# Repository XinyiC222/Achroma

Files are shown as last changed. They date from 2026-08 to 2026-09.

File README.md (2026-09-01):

# Achroma WORK IN PROGRESS

Achroma is a wireless reversible split keyboard with 36 keys that is powered by ZMK. It uses a nine!nano v2 replica from aliexpress. There are two versions of Achroma, the Choc/Choc_v2 compatible one, and the MX compatible one! This is still a work in progress. Theres only a case for the MX version. But there are two different pcb designs based on which one you want to use. Here is the ZMK source files: https://github.com/XinyiC222/zmk-achroma-config I made this after seeing countless split keyboard builds that people where making online and I wanted to join in on the fun! To use it you just have to turn on the on/off button that is connected to the battery. The pcb is designed in kicad and the case is modeled in Fusion360.

Screenshot 2026-08-30 at 11 53 14 AM
Screenshot 2026-08-30 at 11 56 21 AM (MX version)
<h1>Keymap</h1>
Screenshot 2026-08-30 at 11 53 38 AM
Screenshot 2026-08-30 at 11 53 43 AM
Screenshot 2026-08-30 at 11 53 48 AM

<h1>Resources</h1>
<h3>Footprints and References:</h3>

https://github.com/piit79/42keebs-kicad

https://flatfootfox.com/ergogen-part6-reversible-split/

https://github.com/kata0510/Lily58 (this has a great footprint library!)

https://github.com/aroum/PNCATEHO (reversible Choc footprints that fits both versions!)

<h3>Tools</h3>

https://www.keyboard-layout-editor.com/

https://nickcoutsos.github.io/keymap-editor/

https://github.com/adamws/kicad-kbplacer

Fusion360

Kicad

<h1>Mini Guide/ My Process (Work in progress)</h1>

Before starting, you should have already made some kind of electronic project prior to this. It would come off easier if you've designed a pcb before. Reading guides you find online can be super helpful. there are many resources that I didn't link but anything online is helpful. 

1. I first researched and wrote down what I wanted this project to look like at the end. Do I want it to be low profile or MX? Do I want this to be reversible? How much money do I want to spend on this? Do I want to make a custom layout, or do I want to use an existing one? Wireless? etc.
2. I ended up choosing to making my own layout and use ZMK for wireless. So I went ahead and looked for reversible footprints to use. I also wanted to use a battery for it. I then went into keyboard layout editor and made my desired layout.( I only made the left side first)
3. Then I created the schematics in kicad. It included a jst pin, a reversible nice!nano, choc/mx switches, LED, slide switch, and a reset button.
4. then using the .json file from the layout I made in keyboard layout editor and the kbplacer, I organized the keys for the left split.
5. spent a lot of time between editing the schematics, the pcb, and testing new footprint libraries. After a ton of trial and error I made the general layout I wanted.  Screenshot 2026-08-14 at 11 48 46 PM

6. Exported the gerber files and imported them into jlc pcb.
7. I then added 3d models to each of the footprints and import it into fusion to make the case(MX only) Screenshot 2026-08-16 at 12 56 51 PM

8. I looked for components in aliexpress
9. Then I started reading through how to set up ZMK and made the firmware using github actions.
10. After you assemble the pcb and have printed the case out, use a M2 heat insert on all the holes in the case(5 total). Then place the pcb on top and use a M2 screw to tighten it in place.
11. Once you've build the physical item, flash the firmware into the devices. You can learn more about it in the ZMK docs. If you'll like to use the firmware provided, please head to the Firmware folder to download what i have for both the left and the right side.
Screenshot 2026-08-30 at 11 56 32 AM

<h1>Schematic</h1>
Screenshot 2026-09-01 at 12 18 42 PM

<PCB>
Screenshot 2026-09-01 at 12 19 13 PM
Screenshot 2026-09-01 at 12 19 52 PM
Screenshot 2026-09-01 at 12 19 33 PM
Screenshot 2026-09-01 at 12 20 06 PM

<h1>BOM</h1>

Here's the BOM! The Quantity listed below are the amount you need. The links included come in bulks and vary depending on how much you are buyinh. All listed items are required for the build.

| Item | Purpose | Price | Quantity | Source |
| :--- | :--- | :--- | :--- | :--- |
| Nice!Nano V2.0 | Micro controller | $1.95 | 1 | [Aliexpress](https://www.aliexpress.com/item/3256812809465916.html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) |
| Nice!Nano V2.0 | Micro controller | $2.81 | 1 | [Aliexpress](https://www.aliexpress.com/item/3256807196955871.html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) |
| M2 6mm screws | securing the pcb | $1.37 | x10 | [Aliexpress](https://www.aliexpress.com/item/3256807033160325.html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) |
| M2xL3xOD3.2 heat inserts | for the screws | $0.99 | x10 | [Aliexpress](https://www.aliexpress.com/item/3256806651793931.html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) |
| Gateron Milky Switches | switches | $6.91 | x36 | [Aliexpress](https://www.aliexpress.com/item/3256803874880557.html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) |
| SK6812 MINI-E RGB | RGB | $3.61 | x36 | [Aliexpress](https://www.aliexpress.com/item/3256807677321116.html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) |
| Hotswap Sockets | sockets for switches | $1.33 | x36 | [Aliexpress](https://www.aliexpress.com/item/3256807045726008.html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) |
| Horizontal Microswitch | reset button | $2.04 | x2 | [Aliexpress](https://www.aliexpress.com/item/3256806318779497.html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) |
| PH 2.0 Horizontal Header Socket | for the battery | $1.80 | x2 | [Aliexpress](https://www.aliexpress.com/item/3256808824951678.html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) |
| SS12D00G3 Toggle Switch | battery on/off | $0.92 | x2 | [Aliexpress](https://www.aliexpress.com/item/3256808561935510.html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) |
| IN4148 SOD-123 | diodes | $2.08 | x36 | [Aliexpress](https://www.aliexpress.com/item/2255800498728983.html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) |
| 401030 3.7V 110mAh Polymer Lithium Battery | Battery | $9.72 | x2 | [Aliexpress](https://www.aliexpress.us/item/3256811360999976.html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) |
| Case | cover | | x2 | 3d Printed |
| PCB | connect everything together | $9.60 | x2 | JLCPCB |
| **Aliexpress Subtotal** | | **$36.66** | | |
| **JLC Subtotal** | | **$9.60** | | |
| **shipping+tax** | | **+$12.24** | | |
| **Total:** | | **$58.50** | | |

## Credits
<div align="center">
  



</div>

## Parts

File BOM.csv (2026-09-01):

Item | Purpose | Price | Quantity | Source
Nice!Nano V2.0 | Micro controller | $1.95 | 1 | Aliexpress
Nice!Nano V2.0 | Micro comtroller | $2.81 | 1 | Aliexpress
M2 6mm screws | securing the pcb | $1.37 | x10 | Aliexpress
M2xL3xOD3.2 heat inserts | for the screws | $0.99 | x10 | Aliexpress
Gateron Milky Switches | switches | $6.91 | x36 | Aliexpress
SK6812 MINI-E RGB | RGB | $3.61 | x36 | Aliexpress
Hotswap Sockets | sockets for switches | $1.33 | x36 | Aliexpress
Horizontal Microswitch | reset button | $2.04 | x2 | Aliexpress
PH 2.0 Horizontal Header Socket | for the battery | $1.80 | x2 | Aliexpress
SS12D00G3 Toggle Switch | battery on/off | $0.92 | x2 | Aliexpress
IN4148 SOD-123 | diodes | $2.08 | x36 | Aliexpress
3.7V 110mAh Polymer Lithium Battery | Battery | $9.72 | x2 | Aliexpress
PCB | connect everything together | $9.60 | x2 | JLCPCB
Case | cover |  |  | 3d Printed
Aliexpress Subtotal |  | $36.66
JLC Subtotal |  | $9.60
shipping+tax |  | +$12.24
Total: |  | $58.50

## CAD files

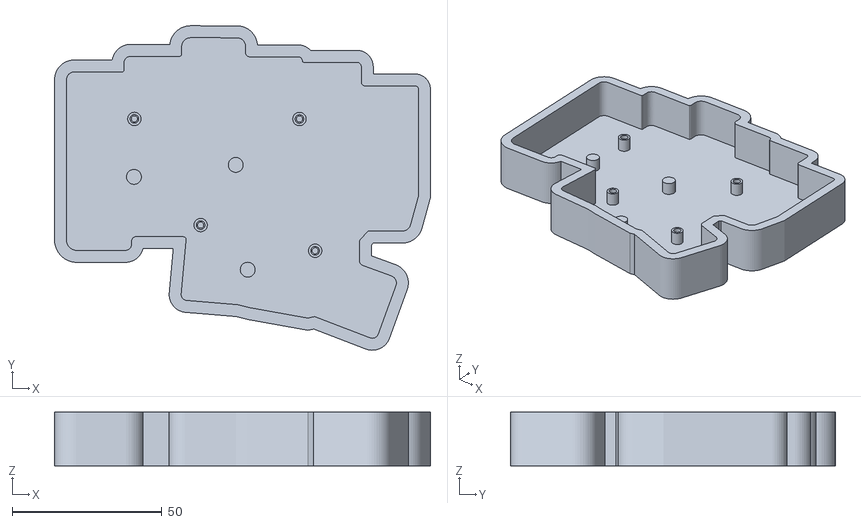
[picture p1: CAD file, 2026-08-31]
3d Print Files/MX_Case_L.stl
125.6 x 108.4 x 18.0

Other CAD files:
Project Files/Fusion/MX_Case_L.step
3d Print Files/MX_Case_R.stl
Project Files/Fusion/MX_Case_R.step

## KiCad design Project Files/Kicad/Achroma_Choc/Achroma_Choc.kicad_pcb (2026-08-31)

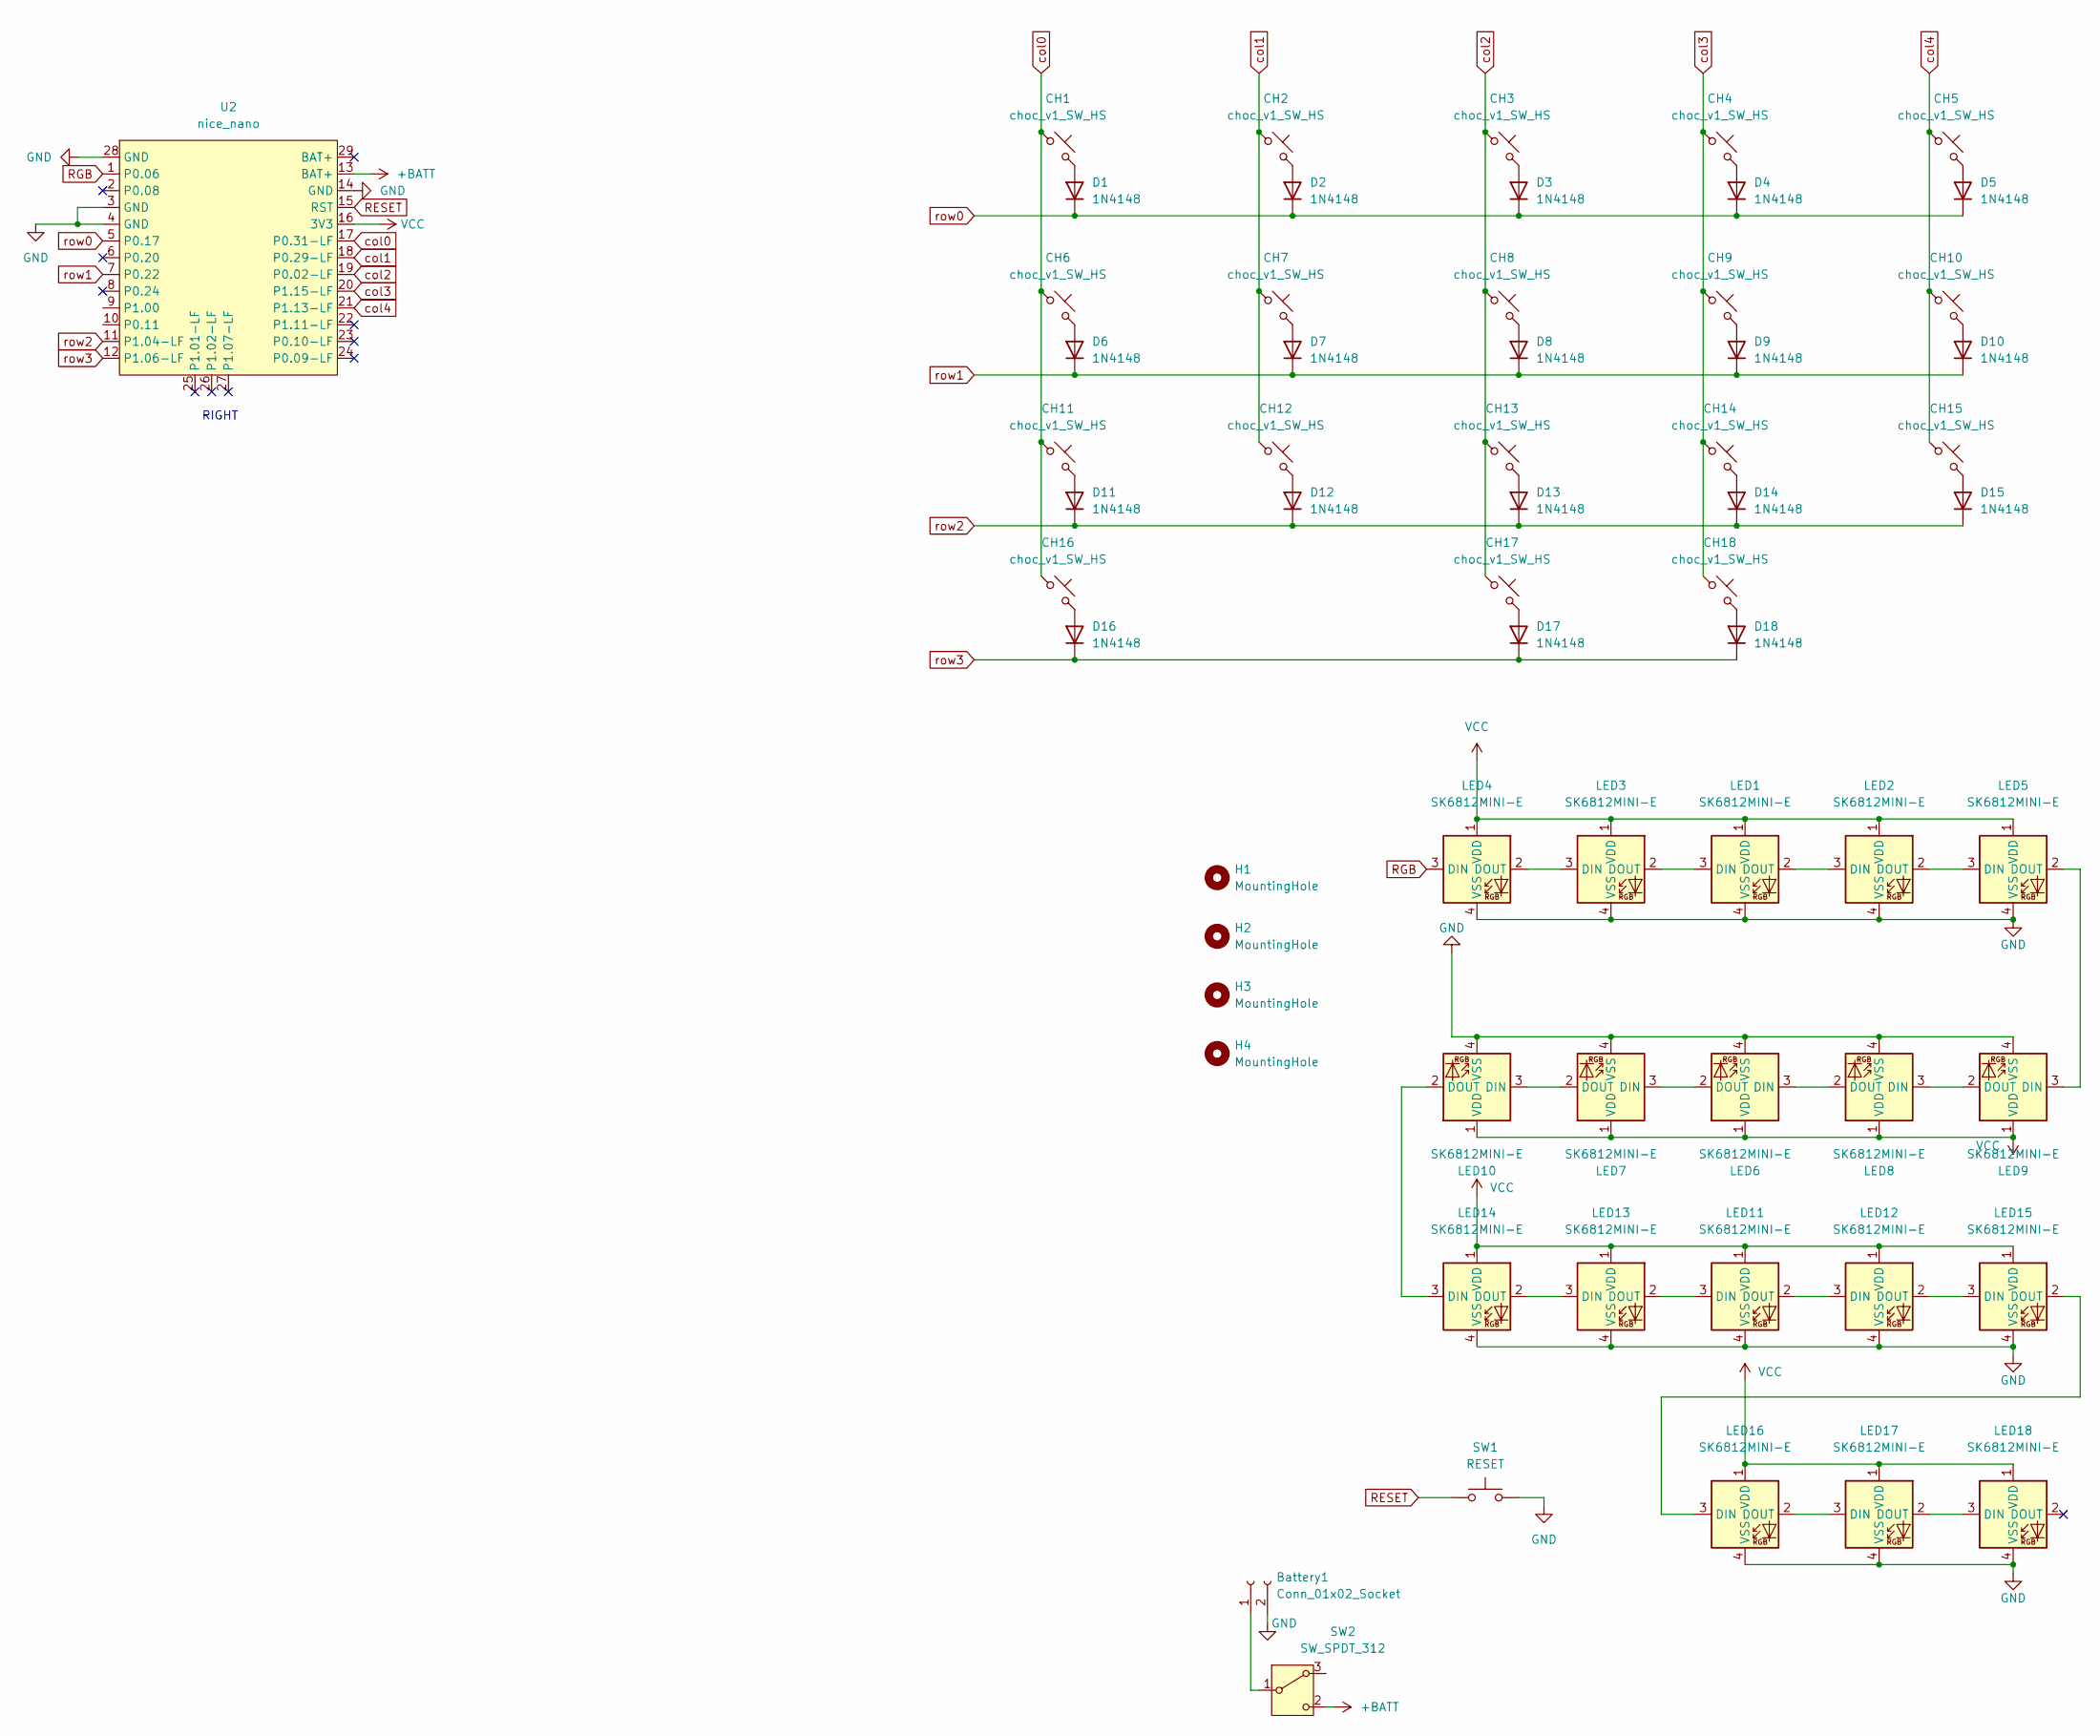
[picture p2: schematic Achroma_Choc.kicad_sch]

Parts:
Battery1: Conn_01x02_Socket; JST_PH_S2B-PH-SM4-TB_1x02-1MP_P2.00mm_Horizontal
CH1, CH2, CH3, CH4, CH5, CH6, CH7, CH8, CH9, CH10, CH11, CH12, CH13, CH14, CH15, CH16, CH17, CH18: choc_v1_SW_HS; Kailh_socket_PG1350_reversible
D1, D2, D3, D4, D5, D6, D7, D8, D9, D10, D11, D12, D13, D14, D15, D16, D17, D18: 1N4148; D_SOD-123 Reversible
H1, H2, H3, H4: MountingHole; MountingHole_2.1mm
LED1, LED2, LED3, LED4, LED5, LED6, LED7, LED8, LED9, LED10, LED11, LED12, LED13, LED14, LED15, LED16, LED17, LED18: SK6812MINI-E; LED_6028R_Reversible
SW1: RESET; TACT_SWITCH_TVBP06
SW2: SW_SPDT_312; SS12D00
U2: nice_nano; nice_nano_AH_Reversible

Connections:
+BATT: SW2.2 (C), U2.13 (BAT+)
GND: Battery1.2, LED1.4 (VSS), LED2.4 (VSS), LED3.4 (VSS), LED4.4 (VSS), LED5.4 (VSS), LED6.4 (VSS), LED7.4 (VSS), LED8.4 (VSS), LED9.4 (VSS), LED10.4 (VSS), LED11.4 (VSS), LED12.4 (VSS), LED13.4 (VSS), LED14.4 (VSS), LED15.4 (VSS), LED16.4 (VSS), LED17.4 (VSS), LED18.4 (VSS), SW1.2, U2.3 (GND), U2.4 (GND), U2.14 (GND), U2.28 (GND)
unnamed: Battery1.1, SW2.1 (B)
unnamed: CH1.2, D1.2 (A)
unnamed: CH2.2, D2.2 (A)
unnamed: CH3.2, D3.2 (A)
unnamed: CH4.2, D4.2 (A)
unnamed: CH5.2, D5.2 (A)
unnamed: CH6.2, D6.2 (A)
unnamed: CH7.2, D7.2 (A)
unnamed: CH8.2, D8.2 (A)
unnamed: CH9.2, D9.2 (A)
unnamed: CH10.2, D10.2 (A)
unnamed: CH11.2, D11.2 (A)
unnamed: CH12.2, D12.2 (A)
unnamed: CH13.2, D13.2 (A)
unnamed: CH14.2, D14.2 (A)
unnamed: CH15.2, D15.2 (A)
unnamed: CH16.2, D16.2 (A)
unnamed: CH17.2, D17.2 (A)
unnamed: CH18.2, D18.2 (A)
unnamed: LED1.3 (DIN), LED3.2 (DOUT)
unnamed: LED1.2 (DOUT), LED2.3 (DIN)
unnamed: LED2.2 (DOUT), LED5.3 (DIN)
unnamed: LED3.3 (DIN), LED4.2 (DOUT)
unnamed: LED5.2 (DOUT), LED9.3 (DIN)
unnamed: LED6.3 (DIN), LED8.2 (DOUT)
unnamed: LED6.2 (DOUT), LED7.3 (DIN)
unnamed: LED8.3 (DIN), LED9.2 (DOUT)
unnamed: LED7.2 (DOUT), LED10.3 (DIN)
unnamed: LED10.2 (DOUT), LED14.3 (DIN)
unnamed: LED11.3 (DIN), LED13.2 (DOUT)
unnamed: LED11.2 (DOUT), LED12.3 (DIN)
unnamed: LED12.2 (DOUT), LED15.3 (DIN)
unnamed: LED13.3 (DIN), LED14.2 (DOUT)
unnamed: LED15.2 (DOUT), LED16.3 (DIN)
unnamed: LED16.2 (DOUT), LED17.3 (DIN)
unnamed: LED17.2 (DOUT), LED18.3 (DIN)
RESET: SW1.1, U2.15 (RST)
RGB: LED4.3 (DIN), U2.1 (P0.06)
VCC: LED1.1 (VDD), LED2.1 (VDD), LED3.1 (VDD), LED4.1 (VDD), LED5.1 (VDD), LED6.1 (VDD), LED7.1 (VDD), LED8.1 (VDD), LED9.1 (VDD), LED10.1 (VDD), LED11.1 (VDD), LED12.1 (VDD), LED13.1 (VDD), LED14.1 (VDD), LED15.1 (VDD), LED16.1 (VDD), LED17.1 (VDD), LED18.1 (VDD), U2.16 (3V3)
col0: CH1.1, CH6.1, CH11.1, CH16.1, U2.17 (P0.31-LF)
col1: CH2.1, CH7.1, CH12.1, U2.18 (P0.29-LF)
col2: CH3.1, CH8.1, CH13.1, CH17.1, U2.19 (P0.02-LF)
col3: CH4.1, CH9.1, CH14.1, CH18.1, U2.20 (P1.15-LF)
col4: CH5.1, CH10.1, CH15.1, U2.21 (P1.13-LF)
row0: D1.1 (K), D2.1 (K), D3.1 (K), D4.1 (K), D5.1 (K), U2.5 (P0.17)
row1: D6.1 (K), D7.1 (K), D8.1 (K), D9.1 (K), D10.1 (K), U2.7 (P0.22)
row2: D11.1 (K), D12.1 (K), D13.1 (K), D14.1 (K), D15.1 (K), U2.11 (P1.04-LF)
row3: D16.1 (K), D17.1 (K), D18.1 (K), U2.12 (P1.06-LF)

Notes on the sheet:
RIGHT

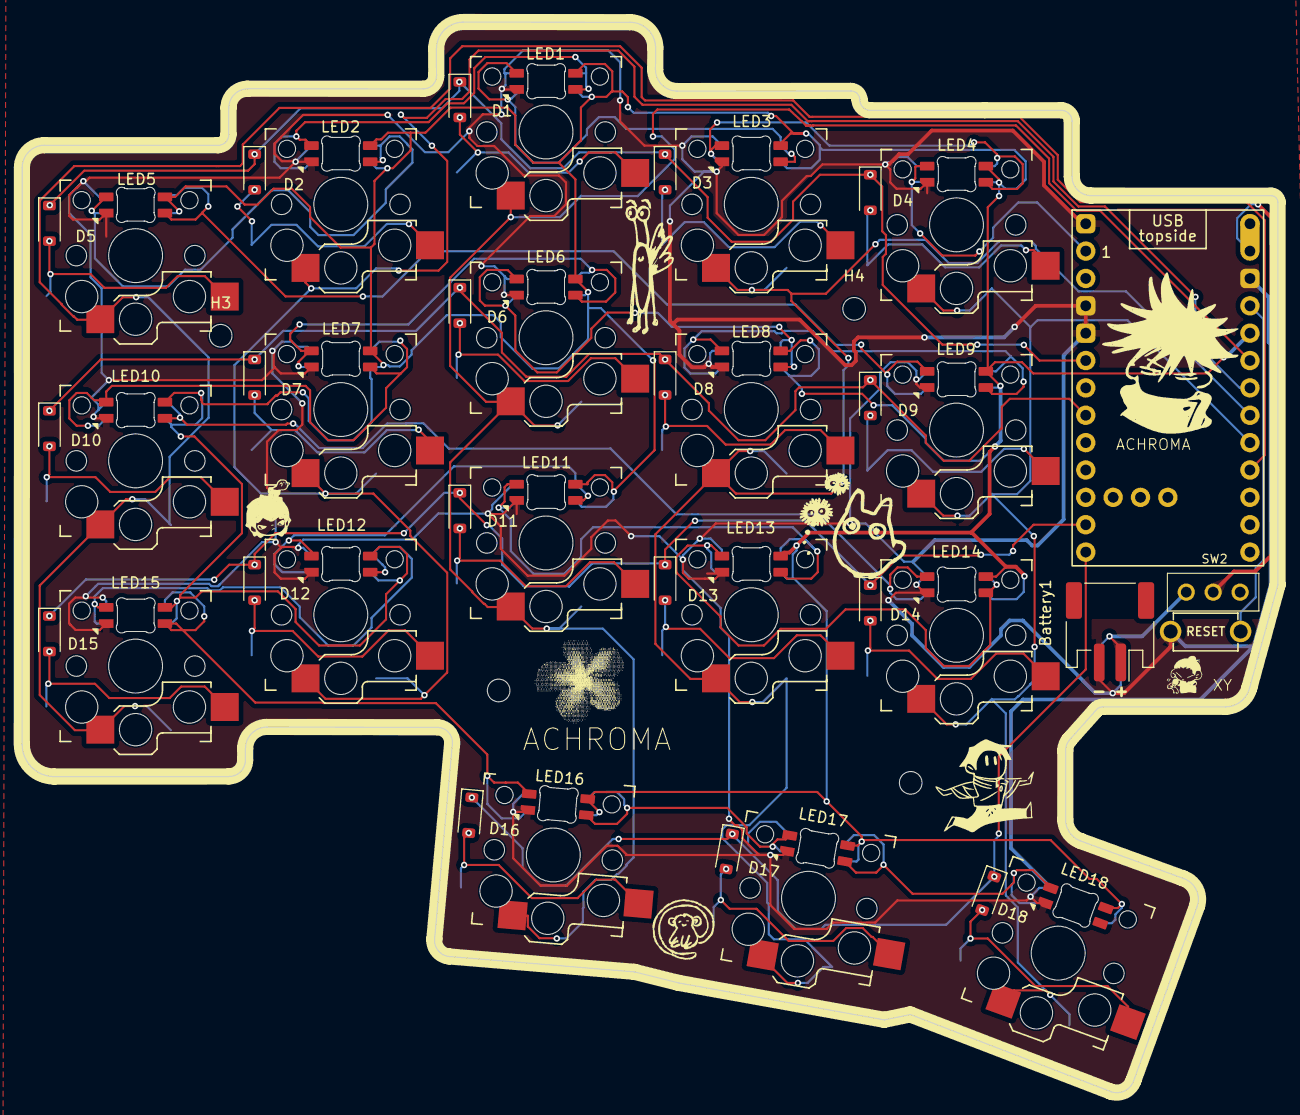
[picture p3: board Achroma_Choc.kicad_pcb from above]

Board: 2 copper layers, 116.6 x 99.4 mm, 62 parts (0 on the bottom side), 50 nets.

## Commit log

2026-08-15 Uploaded MX kicad files
    [Achroma_MX.kicad_pcb, Achroma_MX.kicad_sch]
2026-08-15 Added Choc kicad files
    [Achroma_Choc.kicad_pcb, Achroma_Choc.kicad_sch]
2026-08-15 Updated MX kicad
    [Achroma_MX.kicad_pcb]
2026-08-31 Uploaded project files and zmk
    [MX_Case_L.stl, MX_Case_R.stl]
2026-08-31 updated kicad files
    [Achroma_MX.kicad_pcb]
2026-08-31 updated project files and imported Gerber
    [Achroma_MX.kicad_pcb]
2026-08-31 updated project files
    [Achroma_Choc.kicad_pcb, Achroma_MX.kicad_pcb]
2026-08-31 Add components and pricing to BOM.csv
    [BOM.csv]
2026-08-31 Update JLC Subtotal and shipping in BOM.csv
    [BOM.csv]
2026-08-31 Fix shipping and tax line in BOM.csv
    [BOM.csv]
2026-08-31 Add BOM section with item details and pricing
    Added a Bill of Materials (BOM) section with item details, prices, and sources for the project.
2026-09-01 Update battery details and adjust totals in BOM.csv
    [BOM.csv]
2026-09-01 Enhance README with project details and assembly guide
    Added additional details about the project process, including design considerations and assembly instructions.
2026-09-01 Revise BOM quantities and descriptions
    Updated the BOM quantities and descriptions for clarity. Adjusted item counts and fixed some links.
2026-09-01 Add 'Case' item for 3D printed cover to BOM
    Added a new item 'Case' for a 3D printed cover to the BOM.
    [BOM.csv]
